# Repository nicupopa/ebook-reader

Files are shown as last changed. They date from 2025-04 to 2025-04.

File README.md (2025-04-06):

# OpenBook

## Block Diagram:
Block Diagram

## Bill of Materials:

|Component |Footprint |Link |
|---|---|---|
|BOOT_BUTTON  |BUTTON_CUSYOMV1 |https://industry.panasonic.com/global/en/products/control/switch/light-touch/number/evqpuj02k |
|C1 |ESP32_WROVER_EAGLE-LTSPICE_CC0402 |https://eu.mouser.com/ProductDetail/YAGEO/CC0402MRX5R5BB106?qs=zEY9bCHj09eCmUJdZuS5Lg%3D%3D |
|C1_BAT |ESP32_WROVER_EAGLE-LTSPICE_CC0402 |n/a |
|C1_BAT1 |EAGLE-LTSPICE_CC0402 |n/a |
|C1_BAT2 |EAGLE-LTSPICE_CC0402 |n/a |
|C2 |ESP32_WROVER_EAGLE-LTSPICE_CC0402 |n/a |
|C2_BAT\ |ESP32_WROVER_EAGLE-LTSPICE_CC0402 |n/a |
|C3 |RCL_CPOL-EUCT3528 |n/a |
|C4 |ESP32_WROVER_EAGLE-LTSPICE_CC0402 |n/a |
|C4_USB |ESP32_WROVER_EAGLE-LTSPICE_CC0402 |n/a |
|C5 |ESP32_WROVER_EAGLE-LTSPICE_CC0402 |n/a |
|C5_USB |ESP32_WROVER_EAGLE-LTSPICE_CC0402 |n/a |
|C6 |ESP32_WROVER_EAGLE-LTSPICE_CC0402 |n/a |
|C7 |ESP32_WROVER_EAGLE-LTSPICE_CC0402 |n/a |
|C8 |ESP32_WROVER_EAGLE-LTSPICE_CC0402 |n/a |
|C9 |EAGLE-LTSPICE_CC0402 |n/a |
|C10 |ESP32_WROVER_EAGLE-LTSPICE_CC0402 |n/a |
|C10_SUPERCAP |CPH3225A |https://www.snapeda.com/parts/CPH3225A/Seiko+Instruments/view-part/?ref=eda |
|CHANGE_BUTTON|BUTTON_CUSYOMV1 |https://industry.panasonic.com/global/en/products/control/switch-light-touch/number/evqpuj02k |
|CHG_LED |ADAFRUIT_LEDCHIP-LED0603 |https://www.snapeda.com/parts/KP-1608SURCK/Kingbright/view-part/?ref=search&t=LED%200603 |
|C_DELAY |ESP32_WROVER_EAGLE-LTSPICE_CC0402 |n/a |
|D1 |USBLC6-2SC6Y |https://www.snapeda.com/parts/USBLC6-2SC6Y/STMicroelectronics/view-part/?ref=eda |
|D2 |ESP32_WROVER_AVX---SD0805S020S1R0_AVX_... |https://eu.mouser.com/ProductDetail/KYOCERA-AVX/SD0805S020S1R0?qs=jCA%252BPfw4LHbpkAoSnwrdjw%3D%3D |
|D3 |MBR0530 |https://eu.mouser.com/ProductDetail/KYOCERA-AVX/SD0805S020S1R0?qs=jCA%252BPfw4LHbpkAoSnwrdjw%3D%3D |
|D4 |MBR0530 |https://www.snapeda.com/parts/MBR0530/Onsemi/view-part/?ref=eda |
|D5 |MBR0530 |https://www.snapeda.com/parts/MBR0530/Onsemi/view-part/?ref=eda |
|D6 |PGB1010603MR |https://www.snapeda.com/parts/PGB1010603MR/Littelfuse/view-part/?ref=eda |
|D7 |ESP32_WROVER_AVX---SD0805S020S1R0_AVX_... |https://eu.mouser.com/ProductDetail/KYOCERA-AVX/SD0805S020S1R0?qs=jCA%252BPfw4LHbpkAoSnwrdjw%3D%3D |
|D8 |PGB1010603MR |https://www.snapeda.com/parts/PGB1010603MR/Littelfuse/view-part/?ref=eda |
|D9 |PGB1010603MR |https://www.snapeda.com/parts/PGB1010603MR/Littelfuse/view-part/?ref=eda |
|D10 |PGB1010603MR |https://www.snapeda.com/parts/PGB1010603MR/Littelfuse/view-part/?ref=eda |
|D11 |PGB1010603MR |https://www.snapeda.com/parts/PGB1010603MR/Littelfuse/view-part/?ref=eda |
|D12 |PGB1010603MR |https://www.snapeda.com/parts/PGB1010603MR/Littelfuse/view-part/?ref=eda |
|EPD_C1 |ESP32_WROVER_EAGLE-LTSPICE_CC0402 |n/a |
|EPD_C2 |ESP32_WROVER_EAGLE-LTSPICE_CC0402 |n/a |
|EPD_C5 |ESP32_WROVER_EAGLE-LTSPICE_CC0402 |n/a |
|EPD_C6 |ESP32_WROVER_EAGLE-LTSPICE_CC0402 |n/a |
|EPD_C7 |ESP32_WROVER_EAGLE-LTSPICE_CC0402 |n/a |
|EPD_C8 |ESP32_WROVER_EAGLE-LTSPICE_CC0402 |n/a |
|EPD_C9 |ESP32_WROVER_EAGLE-LTSPICE_CC0402 |n/a |
|EPD_C10 |ESP32_WROVER_EAGLE-LTSPICE_CC0402 |n/a |
|EPD_C11 |ESP32_WROVER_EAGLE-LTSPICE_CC0402 |n/a |
|EPD_C12 |ESP32_WROVER_EAGLE-LTSPICE_CC0402 |n/a |
|IC1 |BD5229G-TR |https://componentsearchengine.com/part-view/BD5229G-TR/ROHM%20Semiconductor |
|IC4 |XC6220A331MR-G |https://componentsearchengine.com/part-view/XC6220A331MR-G/Torex |
|J1 |FH34SRJ-24S-0.5SH_99_ |https://componentsearchengine.com/part-view/XC6220A331MR-G/Torex |
|J2 |SAMACSYS_PARTS_USB4110-GF-A |https://componentsearchengine.com/part-view/USB4110-GF-A/GCT%20(GLOBAL%20CONNECTOR%20TECHNOLOGY |
|J3 |QWIIC_CONNECTORJS-1MM |n/a |
|J4 |112A-TAAR-R03_ATTEND |https://store.comet.srl.ro/Catalogue/Product/43497/ |
|L1 |744043680IND_4828-WE-TPC_WRE |https://eu.mouser.com/ProductDetail/Wurth-Elektronik/744043680?qs=PGXP4M47uW6VkZq%252BkzjrHA%3D%3D |
|PFMF.050.1 |ESP32C6_VARISTORCN1812 |https://www.mouser.co.uk/ProductDetail/EPCOS-TDK/B72520T0350K062?qs=dEfas%2FXlABIszF52uu7vrg%3D%3D |
|Q1 |ESP32_WROVER_SPARKFUN-DISCRETESEMI_MOSFET_...|https://componentsearchengine.com/part-view/DMG2305UX-7/Diodes%20Incorporated |
|Q2 |ESP32_WROVER_SPARKFUN-DISCRETESEMI_MOSFET_...|n/a |
|Q3 |D8 |https://componentsearchengine.com/part-view/SI1308EDL-T1-GE3/Vishay |
|R1 |ESP32_WROVER_EAGLE-LTSPICE_RR0402 |n/a |
|R1-PINH |ESP32_WROVER_EAGLE-LTSPICE_RR0402 |n/a |
|R1-PINH1 |ESP32_WROVER_EAGLE-LTSPICE_RR0402 |n/a |
|R1_BAT |ESP32_WROVER_EAGLE-LTSPICE_RR0402 |n/a |
|R1_PWRUSB |ESP32_WROVER_EAGLE-LTSPICE_RR0402 |n/a |
|R2 |ESP32_WROVER_EAGLE-LTSPICE_RR0402 |https://componentsearchengine.com/part-view/R0402%201%25%20100%20K%20(RC0402FR-07100KL |
|R2-PINH |ESP32_WROVER_EAGLE-LTSPICE_RR0402 |n/a |
|R2-PINH1 |ESP32_WROVER_EAGLE-LTSPICE_RR0402 |n/a |
|R2-USB |ESP32_WROVER_EAGLE-LTSPICE_RR0402 |n/a |
|R2-USB1 |ESP32_WROVER_EAGLE-LTSPICE_RR0402 |n/a |
|R2_BAT |ESP32_WROVER_EAGLE-LTSPICE_RR0402 |n/a |
|R3 |ESP32_WROVER_EAGLE-LTSPICE_RR0402 |n/a |
|R4 |ESP32_WROVER_EAGLE-LTSPICE_RR0402 |n/a |
|R5 |ESP32_WROVER_EAGLE-LTSPICE_RR0402 |n/a |
|R6 |ESP32_WROVER_EAGLE-LTSPICE_RR0402 |n/a |
|R7 |ESP32_WROVER_EAGLE-LTSPICE_RR0402 |n/a |
|R8 |ESP32_WROVER_EAGLE-LTSPICE_RR0402 |n/a |
|R9 |ESP32_WROVER_EAGLE-LTSPICE_RR0402 |n/a |
|R10 |ESP32_WROVER_EAGLE-LTSPICE_RR0402 |n/a |
|RESET_BUTTON |BUTTON_CUSYOMV1 |https://industry.panasonic.com/global/en/products/control/switch/light-touch/number/evqpuj02k |
|R_BOOT |ESP32_WROVER_EAGLE-LTSPICE_RR0402 |n/a |
|R_CAPACITOR  |ESP32_WROVER_EAGLE-LTSPICE_RR0402 |n/a |
|R_CHANGE |ESP32_WROVER_EAGLE-LTSPICE_RR0402 |n/a |
|R_CL1 |ESP32_WROVER_EAGLE-LTSPICE_RR0402 |n/a |
|R_RESET |ESP32_WROVER_EAGLE-LTSPICE_RR0402 |n/a |
|SENSOR2 |ESP32_WROVER_BME680_BME680 |https://www.snapeda.com/parts/BME680/Bosch/view-part/?welcome=home |
|SJ1 |SJ |https://grabcad.com/library/solder-jumpers-1 |
|U1 |W25Q512JVEIQ |https://www.snapeda.com/parts/W25Q512JVEIQ/Winbond+Electronics/view-part/?ref=eda |
|U2 |ESP32-C6-WROOM-1-N8 |https://www.snapeda.com/parts/ESP32-C6-WROOM-1-N8/Espressif+Systems/view-part/?ref=eda |
|U3 |DS3231SN# |https://www.snapeda.com/parts/DS3231SN%23/Analog+Devices/view-part/?ref=eda |
|U4 |MAX17048G+T10 |https://www.snapeda.com/parts/MAX17048G+T10/Analog+Devices/view-part/?ref=eda |
|U5 |ESP32_WROVER_SPARKFUN-IC-POWER_MCP73831 |https://eu.mouser.com/ProductDetail/Microchip-Technology/MCP73831T-2ACI-OT?qs=yUQqVecv4qvbBQBGbHx0Mw%3D%3Dcf|

## Detailed Hardware Description/Specs:

### Microcontroller – ESP32-C6-WROOM-1-N8

- **Processor:** 32-bit RISC-V, up to 160 MHz  
- **Memory:** 512 KB internal SRAM, 8 MB external flash (W25Q512JVEIQ)  
- **Connectivity:** Wi-Fi 6 (802.11ax), Bluetooth 5 (LE), IEEE 802.15.4 (Thread/Zigbee), USB 2.0 (Full-Speed)  
- **Peripherals:** SPI, I²C, UART, PWM, ADC, multiple GPIOs  

### External Memory – W25Q512JVEIQ

- **Capacity:** 512 Mbit (64 MB)  
- **Interface:** Quad SPI (QPI)  
- **Operating Frequency:** Up to 133 MHz  
- **Supply Voltage:** 2.7 V to 3.6 V  
- **Features:** high endurance (100k write/erase cycles)

### Real-Time Clock – DS3231SN#

- **Accuracy:** ±2 ppm from 0°C to +40°C  
- **Interface:** I²C  
- **Features:** Integrated temperature-compensated crystal oscillator (TCXO)  
- **Voltage Range:** 2.3 V to 5.5 V  
- **Additional:** Battery backup support, 2 programmable alarms, 1Hz square wave output

### Battery Monitor – MAX17048G+T10

- **Function:** Fuel gauge for single-cell Li-ion/Li-Po batteries
- **Interface:** I²C  
- **Voltage Range:** 2.5 V to 4.5 V  
- **Power Consumption:** Ultra-low quiescent current (~23 µA)

### Charge Controller – MCP73831

- **Battery Type:** Single-cell Li-ion/Li-Po  
- **Charging Current:** Programmable up to 500 mA  
- **Interface:** Standalone (no I²C/SPI)  
- **Input Voltage:** 3.75 V to 6 V  
- **Status Output:** Charge status indication via LED

### Environmental Sensor – BME688

- **Measurements:** Temperature, humidity, pressure, gas (VOC, air quality)  
- **Interface:** I²C, SPI  
- **Temperature Range:** -40 °C to +85 °C  
- **Gas Sensor:** AI-based VOC and gas mixture detection  
- **Power Consumption:** Ultra-low power (ideal for mobile/wearables)

### E-Paper Display

- **Interface:** SPI  
- **Resolution:** 800×480
- **Power Usage:** Extremely low (only consumes power during refresh)  
- **Features:** Excellent sunlight readability, wide viewing angles

### Qwiic Connector

- **Type:** JST SH 1.0 mm 4-pin connector  
- **Purpose:** Standardized I²C interconnect for sensors/modules  
- **Voltage:** 3.3 V logic  
- **Pins:** SDA, SCL, VCC, GND  

### SD Memory Card Connector – 112A-TAAR-R03

- **Type:** MicroSD card socket
- **Interface:** SPI or SDIO  
- **Voltage:** Typically 3.3 V logic  
- **Features:** Push-push eject mechanism, card detect switch  
- **Use Case:** Data logging, file storage, media playback

## ESP32-C6 Pin Usage:

| Device | ESP32-C6 Pin | Connected Component | Function |
|:---|:---|:---|:---|
| U2 - ESP32-C6 | GPIO0 | BOOT button | Enables bootloader mode on startup (input)  |
| U2 - ESP32-C6 | GPIO1 | UART TX | Serial communication for debugging/flashing |
| U2 - ESP32-C6 | GPIO2 | UART RX | Serial communication for debugging/flashing |
| U2 - ESP32-C6 | GPIO3 | BME688 (I²C SDA) | Environmental sensor data line |
| U2 - ESP32-C6 | GPIO4 | BME688 (I²C SCL) | Environmental sensor clock line |
| U2 - ESP32-C6 | GPIO5 | MAX17048 (I²C SDA) | Battery monitor data line (shared bus) |
| U2 - ESP32-C6 | GPIO6 | MAX17048 (I²C SCL) | Battery monitor clock line (shared bus) |
| U2 - ESP32-C6 | GPIO7 | Qwiic Connector SDA | I²C communication (shared with sensors) |
| U2 - ESP32-C6 | GPIO8 | Qwiic Connector SCL | I²C communication (shared with sensors) |
| U2 - ESP32-C6 | GPIO9 | DS3231 RTC SDA | I²C data line for real-time clock |
| U2 - ESP32-C6 | GPIO10 | DS3231 RTC SCL | I²C clock line for real-time clock |
| U2 - ESP32-C6 | GPIO18 | E-Paper Display (SPI MOSI) | Serial data out to display |
| U2 - ESP32-C6 | GPIO19 | E-Paper Display (SPI CLK)  | Serial clock for display communication |
| U2 - ESP32-C6 | GPIO20 | E-Paper Display (CS) | Chip select line |
| U2 - ESP32-C6 | GPIO21 | E-Paper Display (DC) | Data/Command control pin |
| U2 - ESP32-C6 | GPIO22 | E-Paper Display (RST) | Reset line for display |
| U2 - ESP32-C6 | GPIO23 | E-Paper Display (BUSY) | Busy status signal input |
| U2 - ESP32-C6 | GPIO13 | SD Card (SPI CS) | Chip select line for SD card |
| U2 - ESP32-C6 | GPIO14 | SD Card (SPI MISO) | Master In Slave Out - reads from SD |
| U2 - ESP32-C6 | GPIO15 | SD Card (SPI MOSI) | Master Out Slave In - writes to SD |
| U2 - ESP32-C6 | GPIO16 | SD Card (SPI CLK) | SPI clock for SD card communication |

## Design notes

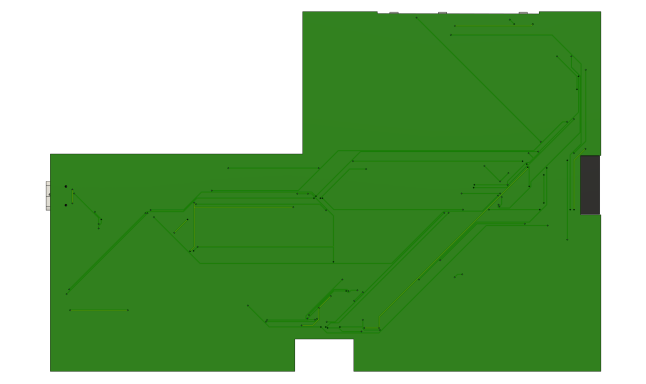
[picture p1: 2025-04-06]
Images/pcb_view_bottom.png

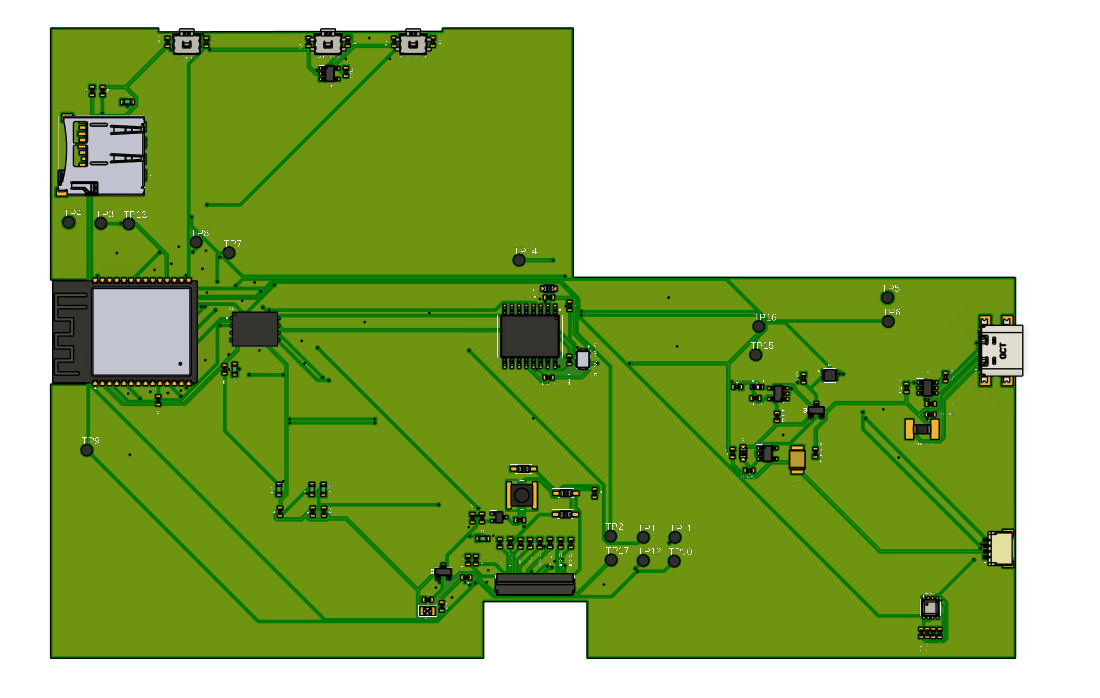
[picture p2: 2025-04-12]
Images/3D_PCB.png

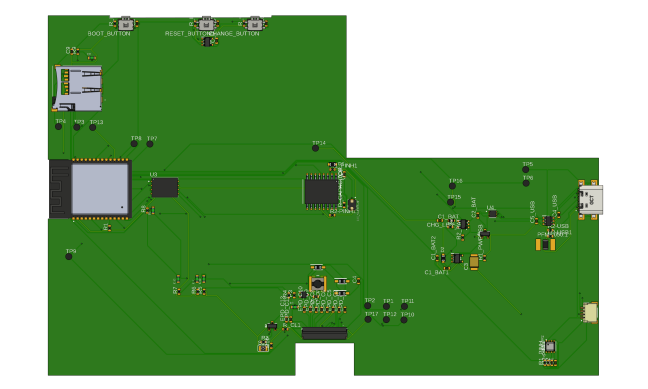
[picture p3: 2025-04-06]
Images/pcb_view_top.png

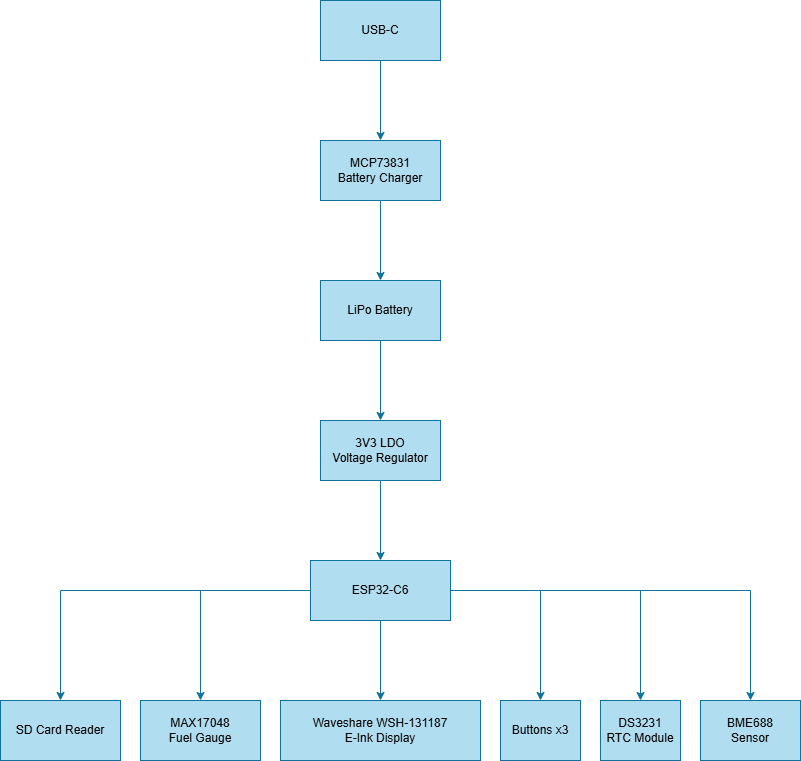
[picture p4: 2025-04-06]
Images/Block Diagram.png

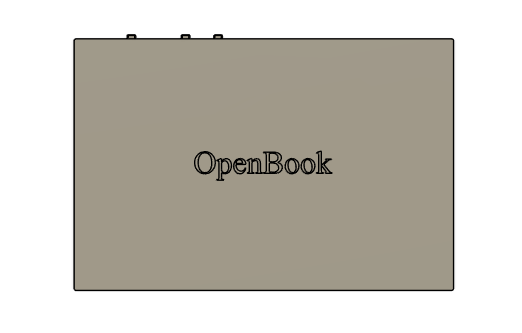
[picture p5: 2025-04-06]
Images/case_view_bottom.png

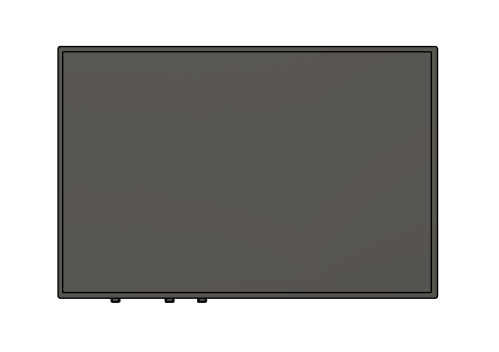
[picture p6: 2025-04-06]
Images/case_view_top.png

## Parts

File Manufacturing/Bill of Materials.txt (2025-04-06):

Partlist exported from Fusion Hub: nicu   Project: OPENBOOK  Board: PCB v40 at 06/04/2025 15:30

Qty Value                                                                          Device                                                                         Package                                                Parts                                                                                       Description                                                                                                                                                                                                                                                                                                                                                                                                                                                                                          ARROW_PART_NUMBER ARROW_PRICE-STOCK AVAILABILITY CENTROID_NOT_SPECIFIED CHECK_PRICES                                                                           COPYRIGHT                                                DATASHEET                              DESCRIPTION                                                                                        DIGIKEY_DESCRIPTION                                                                                                                                                                                                      DIGIKEY_PART_NUMBER                           HEIGHT                                                                                LEAD_FREE                                                          MANUFACTURER   MANUFACTURER_NAME                 MANUFACTURER_PART_NUMBER MF                  MFR_NAME          MOUSER_PART_NUMBER    MOUSER_PRICE-STOCK                                                                                        MOUSER_TESTING_PART_NUMBER MOUSER_TESTING_PRICE-STOCK MP                                                                                                                  MPN                                                                                                  PACKAGE                     POPULARITY          PREFIX PRICE                        PROD_ID    PURCHASE-URL                                                                                                                                ROHS SNAPEDA_LINK                                                                       SPICEMODEL                                                                                                                                      SPICEPREFIX TEMPERATURE_RANGE_HIGH                                                                  TEMPERATURE_RANGE_LOW TP_SIGNAL_NAME VALUE             
1                                                                                  ADAFRUIT_LEDCHIP-LED0603                                                       ADAFRUIT_CHIP-LED0603                                  CHG_LED                                                                                     LED                                                                                                                                                                                                                                                                                                                                                                                                                                                                                                                                                                                                                                                                                                                                                                                                                                                                                                                                                                                                                                                                                                                                                                                                                                                                                                                                                                                                                                                                                                                                                                                                                                                                                                                                                                                                                                                                                                                                                                                                                                                                                                                                                                                                                                                                                                                                                                                                                                                                                 
3                                                                                  BUTTON_CUSYOMV1                                                                MYBUTTON                                               BOOT_BUTTON, CHANGE_BUTTON, RESET_BUTTON                                                                                                                                                                                                                                                                                                                                                                                                                                                                                                                                                                                                                                                                                                                                                                                                                                                                                                                                                                                                                                                                                                                                                                                                                                                                                                                                                                                                                                                                                                                                                                                                                                                                                                                                                                                                                                                                                                                                                                                                                                                                                                                                                                                                                                                                                                                                                                                                                                                                                                                                        
1                                                                                  ESP32_WROVER_EAGLE-LTSPICE_RR0402                                              ESP32_WROVER_EAGLE-LTSPICE_R0402                       R1                                                                                          RESISTOR, European symbol                                                                                                                                                                                                                                                                                                                                                                                                                                                                                                                                                                                                                                                                                                                                                                                                                                                                                                                                                                                                                                                                                                                                                                                                                                                                                                                                                                                                                                                                                                                                                                                                                                                                                                                                                                                                                                                                                                                                                                                                                                                                                                                                                NONE                                                                                                                                            R                                                                                                                                                          
1                                                                                  SJ                                                                             SJ                                                     SJ1                                                                                         SMD solder JUMPER                                                                                                                                                                                                                                                                                                                                                                                                                                                                                                                                                                                                                                                                                                                                                                                                                                                                                                                                                                                                                                                                                                                                                                                                                                                                                                                                                                                                                                                                                                                                                                                                                                                                                                                                                                                                                                                 3                                                                                                                                                                                                                                                                                                                                                                                                                                                                                                                                                                                                                 
1   0.1uF/50V                                                                      EAGLE-LTSPICE_CC0402                                                           EAGLE-LTSPICE_C0402                                    EPD_C5                                                                                      CAPACITOR, European symbol                                                                                                                                                                                                                                                                                                                                                                                                                                                                                                                                                                                                                                                                                                                                                                                                                                                                                                                                                                                                                                                                                                                                                                                                                                                                                                                                                                                                                                                                                                                                                                                                                                                                                                                                                                                                                                                                                                                                                                                                                                                                                                                                               NONE                                                                                                                                            C                                                                                                                                                          
1   0.47                                                                           ESP32_WROVER_EAGLE-LTSPICE_RR0402                                              ESP32_WROVER_EAGLE-LTSPICE_R0402                       R3                                                                                          RESISTOR, European symbol                                                                                                                                                                                                                                                                                                                                                                                                                                                                                                                                                                                                                                                                                                                                                                                                                                                                                                                                                                                                                                                                                                                                                                                                                                                                                                                                                                                                                                                                                                                                                                                                                                                                                                                                                                                                                                                                                                                                                                                                                                                                                                                                                NONE                                                                                                                                            R                                                                                                                                                          
1   100K                                                                           ESP32_WROVER_EAGLE-LTSPICE_RR0402                                              ESP32_WROVER_EAGLE-LTSPICE_R0402                       R1_PWRUSB                                                                                   RESISTOR, European symbol                                                                                                                                                                                                                                                                                                                                                                                                                                                                                                                                                                                                                                                                                                                                                                                                                                                                                                                                                                                                                                                                                                                                                                                                                                                                                                                                                                                                                                                                                                                                                                                                                                                                                                                                                                                                                                                                                                                                                                                                                                                                                                                                                NONE                                                                                                                                            R                                                                                                                                                          
7   100nF                                                                          EAGLE-LTSPICE_CC0402                                                           EAGLE-LTSPICE_C0402                                    C1, C2, C4_USB, C6, C8, C10, C_DELAY                                                        CAPACITOR, European symbol                                                                                                                                                                                                                                                                                                                                                                                                                                                                                                                                                                                                                                                                                                                                                                                                                                                                                                                                                                                                                                                                                                                                                                                                                                                                                                                                                                                                                                                                                                                                                                                                                                                                                                                                                                                                                                                                                                                                                                                                                                                                                                                                               NONE                                                                                                                                            C                                                                                                                                                          
1   100nF                                                                          ESP32_WROVER_EAGLE-LTSPICE_CC0402                                              ESP32_WROVER_EAGLE-LTSPICE_C0402                       C9                                                                                          CAPACITOR, European symbol                                                                                                                                                                                                                                                                                                                                                                                                                                                                                                                                                                                                                                                                                                                                                                                                                                                                                                                                                                                                                                                                                                                                                                                                                                                                                                                                                                                                                                                                                                                                                                                                                                                                                                                                                                                                                                                                                                                                                                                                                                                                                                                                               NONE                                                                                                                                            C                                                                                                                                                          
1   100uF TANT                                                                     RCL_CPOL-EUCT3528                                                              RCL_CT3528                                             C3                                                                                          POLARIZED CAPACITOR, European symbol                                                                                                                                                                                                                                                                                                                                                                                                                                                                                                                                                                                                                                                                                                                                                                                                                                                                                                                                                                                                                                                                                                                                                                                                                                                                                                                                                                                                                                                                                                                                                                                                                                                                                                                                                                                                                              0                                                                                                                                                                                                                                                                                                                                                                                                                                                      C
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

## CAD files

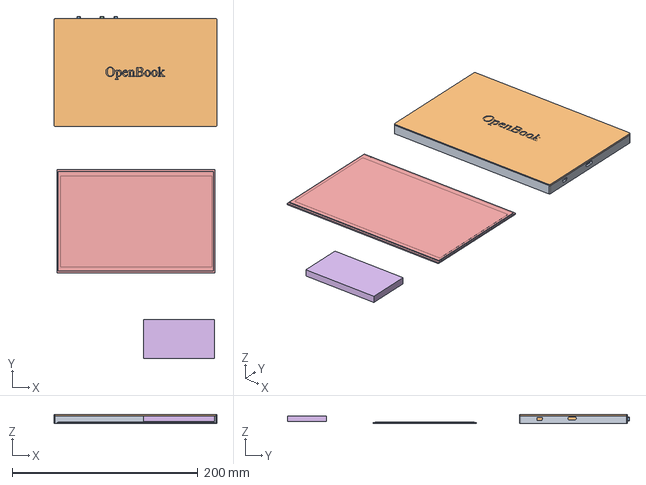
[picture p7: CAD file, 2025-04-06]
Mechanical/OpenBook_exploded.step
175.3 x 368.2 x 9.86 mm

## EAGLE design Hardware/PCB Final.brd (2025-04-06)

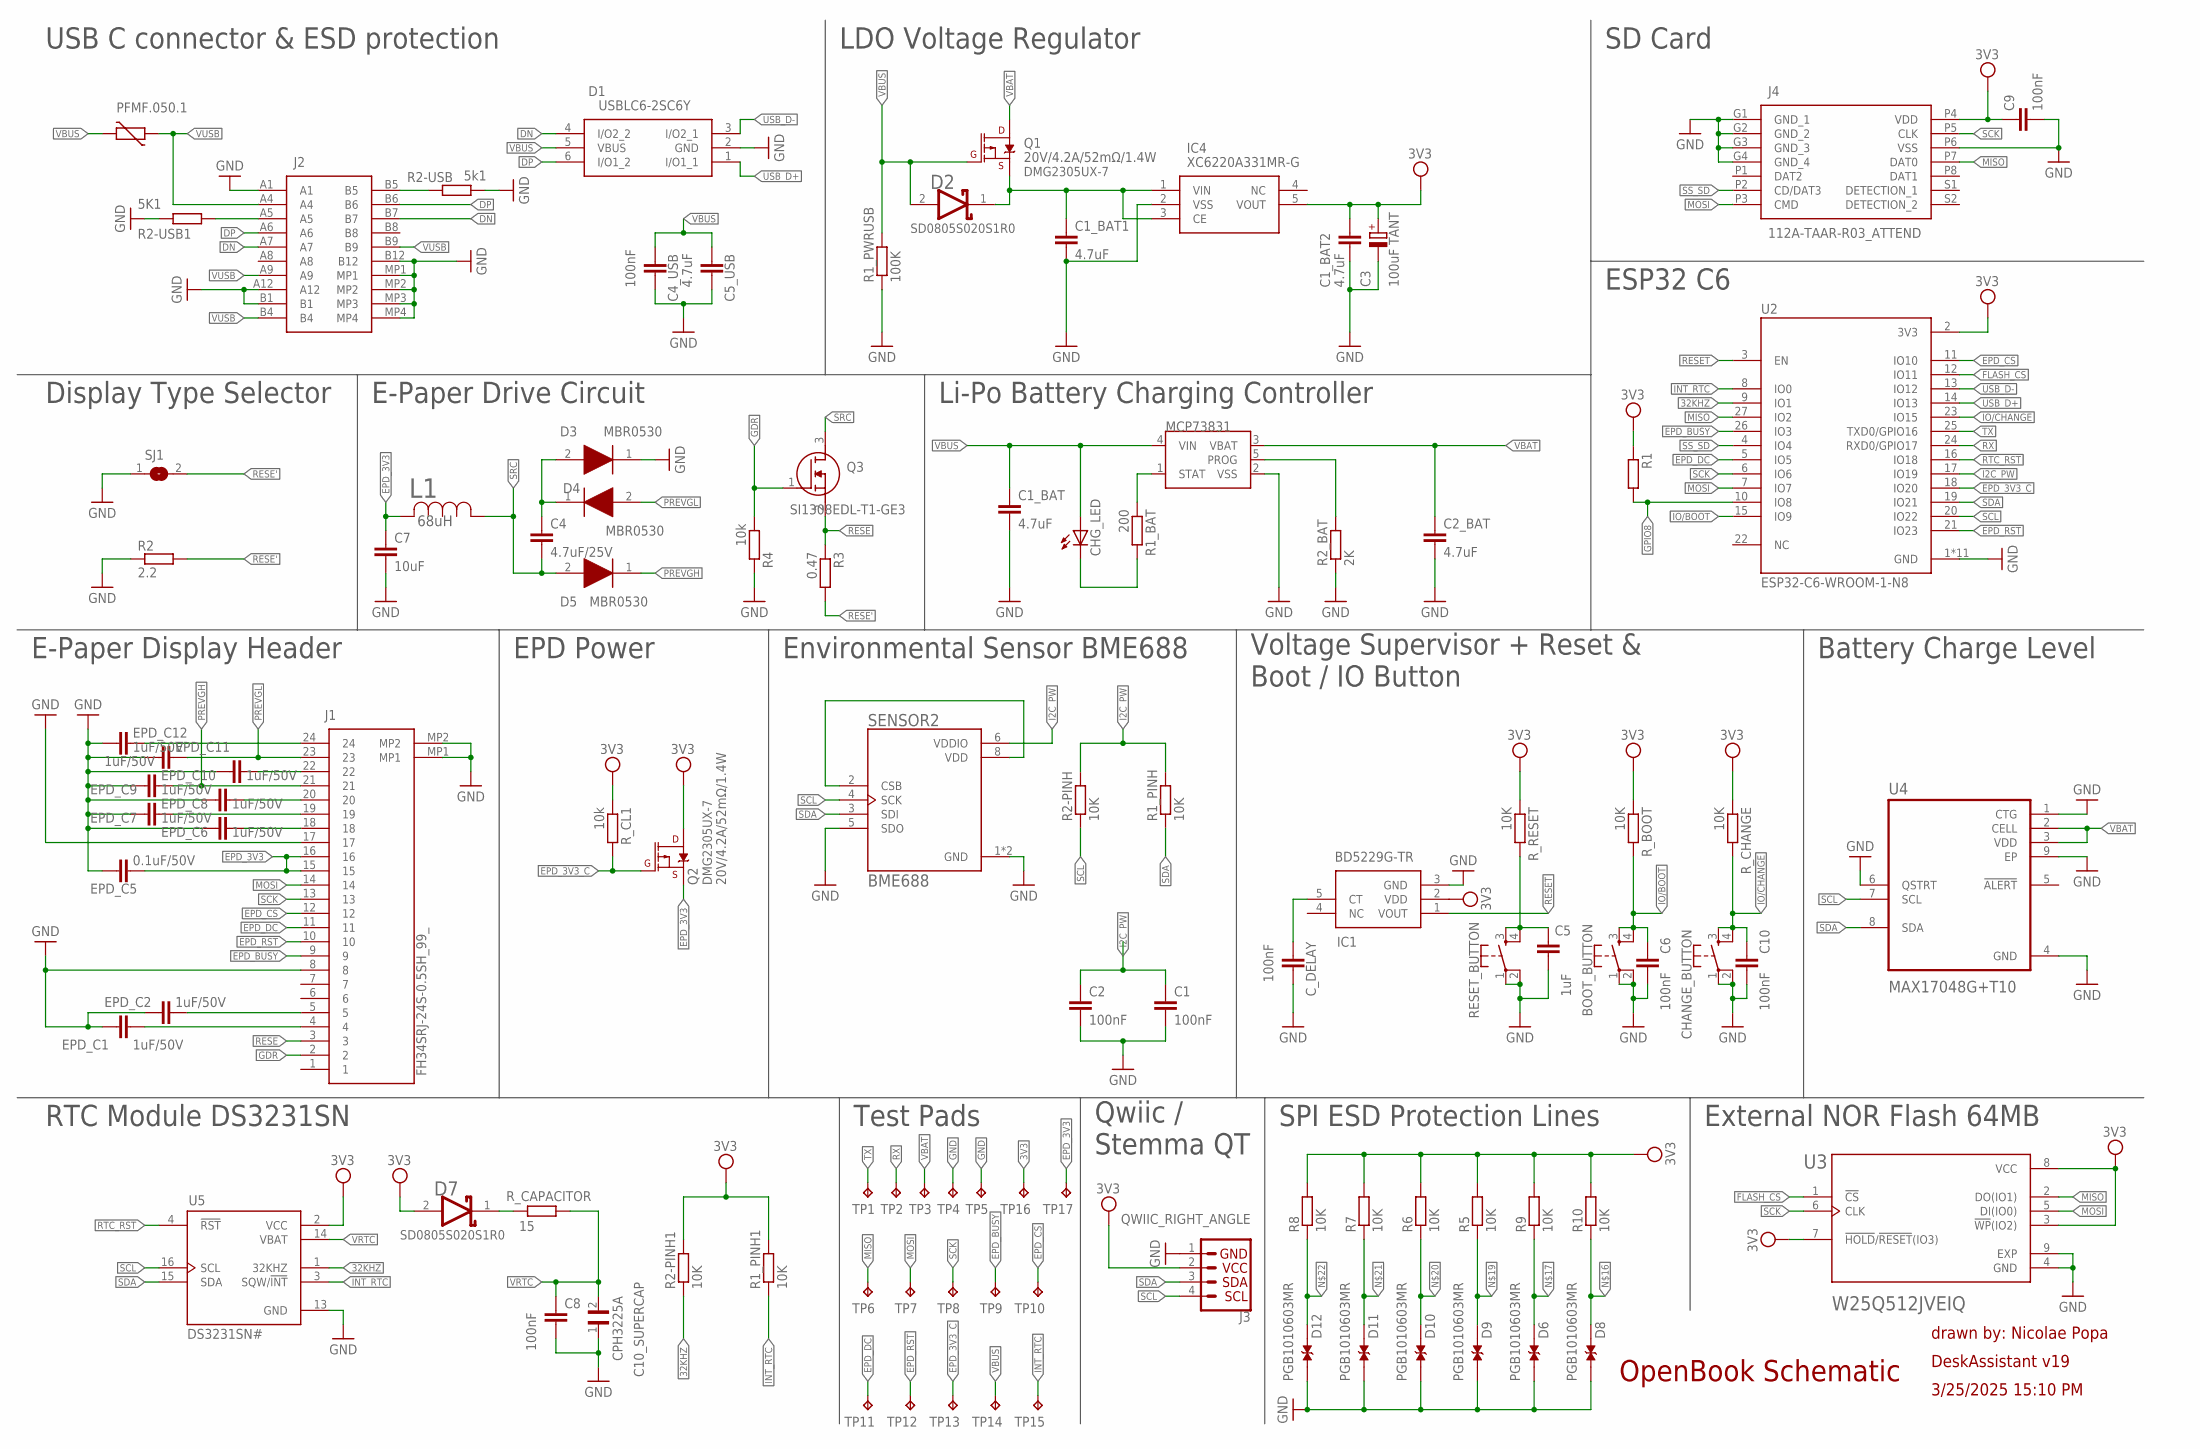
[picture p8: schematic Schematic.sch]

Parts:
BOOT_BUTTON: BUTTON_CUSYOMV1; MYBUTTON
C1, C2, C4_USB, C6, C8, C10: 100nF; EAGLE-LTSPICE_C0402
C1_BAT, C1_BAT1, C1_BAT2, C2_BAT, C5_USB: 4.7uF; EAGLE-LTSPICE_C0402
C3: 100uF TANT; RCL_CT3528
C4: 4.7uF/25V; EAGLE-LTSPICE_C0402
C5: 1uF; EAGLE-LTSPICE_C0402
C7: 10uF; EAGLE-LTSPICE_C0402
C9: 100nF; ESP32_WROVER_EAGLE-LTSPICE_C0402
C10_SUPERCAP: CPH3225A; CAPCP3225X100N
CHANGE_BUTTON: BUTTON_CUSYOMV1; MYBUTTON
CHG_LED: ADAFRUIT_LEDCHIP-LED0603; ADAFRUIT_CHIP-LED0603
C_DELAY: 100nF; EAGLE-LTSPICE_C0402
D1: USBLC6-2SC6Y; SOT95P280X145-6N
D2: ESP32_WROVER_AVX---SD0805S020S1R0_AVX_SD0805S020S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; ESP32_WROVER_AVX---SD0805S020S1R0_AVX_SD0805S020S1R0_0
D3, D4, D5: MBR0530; SOD3716X135N
D6, D8, D9, D10, D11, D12: PGB1010603MR; DIOC1608X36N
D7: SD0805S020S1R0; ESP32_WROVER_AVX---SD0805S020S1R0_AVX_SD0805S020S1R0_0
EPD_C1, EPD_C2, EPD_C6, EPD_C7, EPD_C8, EPD_C9, EPD_C10, EPD_C11, EPD_C12: 1uF/50V; EAGLE-LTSPICE_C0402
EPD_C5: 0.1uF/50V; EAGLE-LTSPICE_C0402
IC1: BD5229G-TR; SOT95P280X125-5N
IC4: XC6220A331MR-G; SOT95P280X120-5N
J1: FH34SRJ-24S-0.5SH_99_; FH34SRJ24S05SH99
J2: SAMACSYS_PARTS_USB4110-GF-A; SAMACSYS_PARTS_USB4110GFA
J3: QWIIC_RIGHT_ANGLE; JST04_1MM_RA
J4: 112A-TAAR-R03_ATTEND; 112ATAARR03ATTEND
L1: 68uH; IND_4828-WE-TPC_WRE
PFMF.050.1: ESP32C6_VARISTORCN1812; ESP32C6_VARISTOR_CT/CN1812
Q1, Q2: 20V/4.2A/52mΩ/1.4W; ESP32_WROVER_SPARKFUN-DISCRETESEMI_SOT23-3
Q3: SI1308EDL-T1-GE3; SOT65P210X110-3N
R1: ESP32_WROVER_EAGLE-LTSPICE_RR0402; ESP32_WROVER_EAGLE-LTSPICE_R0402
R1_BAT: 200; ESP32_WROVER_EAGLE-LTSPICE_R0402
R1_PINH, R1_PINH1, R2-PINH, R2-PINH1, R5, R6, R7, R8, R9, R10: 10K; ESP32_WROVER_EAGLE-LTSPICE_R0402
R1_PWRUSB: 100K; ESP32_WROVER_EAGLE-LTSPICE_R0402
R2: 2.2; ESP32_WROVER_EAGLE-LTSPICE_R0402
R2-USB: 5k1; ESP32_WROVER_EAGLE-LTSPICE_R0402
R2-USB1: 5K1; ESP32_WROVER_EAGLE-LTSPICE_R0402
R2_BAT: 2K; ESP32_WROVER_EAGLE-LTSPICE_R0402
R3: 0.47; ESP32_WROVER_EAGLE-LTSPICE_R0402
R4: 10k; ESP32_WROVER_EAGLE-LTSPICE_R0402
RESET_BUTTON: BUTTON_CUSYOMV1; MYBUTTON
R_BOOT: 10K; ESP32_WROVER_EAGLE-LTSPICE_R0402
R_CAPACITOR: 15; ESP32_WROVER_EAGLE-LTSPICE_R0402
R_CHANGE: 10K; ESP32_WROVER_EAGLE-LTSPICE_R0402
R_CL1: 10k; ESP32_WROVER_EAGLE-LTSPICE_R0402
R_RESET: 10K; ESP32_WROVER_EAGLE-LTSPICE_R0402
SENSOR2: BME688; ESP32_WROVER_BME680_PSON80P300X300X100-8N
SJ1: SJ
TP1, TP2, TP3, TP4, TP5, TP6, TP7, TP8, TP9, TP10, TP11, TP12, TP13, TP14, TP15, TP16, TP17: TPTP20R; TP20R
U1: MCP73831; ESP32_WROVER_SPARKFUN-IC-POWER_SOT23-5
U2: ESP32-C6-WROOM-1-N8; XCVR_ESP32-C6-WROOM-1-N8
U3: W25Q512JVEIQ; SON127P600X800X80-9N
U4: MAX17048G+T10; SON50P200X200X80-9N
U5: DS3231SN#; SOIC127P1032X265-16N

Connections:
3V3: C1_BAT2.1, C3.+, C9.1, D7.2 (ANODE), IC1.2 (VDD), IC4.5 (VOUT), J3.2, J4.P4 (VDD), Q2.3 (D), R1.1, R1_PINH1.2, R2-PINH1.2, R5.2, R6.2, R7.2, R8.2, R9.2, R10.2, R_BOOT.1, R_CHANGE.1, R_CL1.1, R_RESET.1, TP16.TP, U2.2 (3V3), U3.3 (!WP!(IO2)), U3.7 (!HOLD!/!RESET!(IO3)), U3.8 (VCC), U5.2 (VCC)
32KHZ: R2-PINH1.1, U2.9 (IO1), U5.1 (32KHZ)
DN: D1.4 (I/O2_2), J2.A7, J2.B7
DP: D1.6 (I/O1_2), J2.A6, J2.B6
EPD_3V3: C7.1, EPD_C5.1, J1.15, J1.16, L1.2, Q2.2 (S), TP17.TP
EPD_3V3_C: Q2.1 (G), R_CL1.2, TP13.TP, U2.18 (IO20)
EPD_BUSY: J1.9, TP9.TP, U2.26 (IO3)
EPD_CS: J1.12, TP10.TP, U2.11 (IO10)
EPD_DC: J1.11, TP11.TP, U2.5 (IO5)
EPD_RST: J1.10, TP12.TP, U2.21 (IO23)
FLASH_CS: U2.12 (IO11), U3.1 (!CS)
GDR: J1.2, Q3.1 (G), R4.1
GND: BOOT_BUTTON.1, BOOT_BUTTON.2, C1.2, C1_BAT.2, C1_BAT1.2, C1_BAT2.2, C2.2, C2_BAT.2, C3.-, C4_USB.2, C5.2, C5_USB.2, C6.2, C7.2, C8.2, C9.2, C10.2, C10_SUPERCAP.1, CHANGE_BUTTON.1, CHANGE_BUTTON.2, C_DELAY.2, D1.2 (GND), D3.1 (K), D6.1, D8.1, D9.1, D10.1, D11.1, D12.1, EPD_C1.2, EPD_C2.2, EPD_C5.2, EPD_C6.2, EPD_C7.2, EPD_C8.2, EPD_C9.2, EPD_C10.2, EPD_C11.2, EPD_C12.2, IC1.3 (GND), IC4.2 (VSS), J1.8, J1.17, J1.MP1, J1.MP2, J2.A1, J2.A12, J2.B1, J2.B12, J2.MP1, J2.MP2, J2.MP3, J2.MP4, J3.1, J4.G1 (GND_1), J4.G2 (GND_2), J4.G3 (GND_3), J4.G4 (GND_4), J4.P6 (VSS), R1_PWRUSB.1, R2.1, R2-USB.2, R2-USB1.1, R2_BAT.1, R4.2, RESET_BUTTON.1, RESET_BUTTON.2, SENSOR2.1 (GND), SENSOR2.5 (SDO), SENSOR2.7 (GND), SJ1.1, TP4.TP, TP5.TP, U1.2 (VSS), U2.1 (GND), U2.28 (GND), U2.29_1 (GND), U2.29_2 (GND), U2.29_3 (GND), U2.29_4 (GND), U2.29_5 (GND), U2.29_6 (GND), U2.29_7 (GND), U2.29_8 (GND), U2.29_9 (GND), U3.4 (GND), U3.9 (EXP), U4.1 (CTG), U4.4 (GND), U4.6 (QSTRT), U4.9 (EP), U5.13 (GND)
GPIO8: R1.2, U2.10 (IO8)
I2C_PW: C1.1, C2.1, R1_PINH.2, R2-PINH.2, SENSOR2.6 (VDDIO), U2.17 (IO19)
INT_RTC: R1_PINH1.1, TP15.TP, U2.8 (IO0), U5.3 (SQW/!INT)
IO/BOOT: BOOT_BUTTON.3, BOOT_BUTTON.4, C6.1, R_BOOT.2, U2.15 (IO9)
IO/CHANGE: C10.1, CHANGE_BUTTON.3, CHANGE_BUTTON.4, R_CHANGE.2, U2.23 (IO15)
MISO: J4.P7 (DAT0), TP6.TP, U2.27 (IO2), U3.2 (DO(IO1))
MOSI: J1.14, J4.P3 (CMD), TP7.TP, U2.7 (IO7), U3.5 (DI(IO0))
unnamed: J2.A5, R2-USB1.2
unnamed: C1_BAT1.1, D2.1 (CATHODE), IC4.1 (VIN), IC4.3 (CE), Q1.2 (S)
unnamed: R1_BAT.1, U1.1 (STAT)
unnamed: C4.1, D3.2 (A), D4.1 (K)
unnamed: CHG_LED.C, R1_BAT.2
unnamed: EPD_C12.1, J1.24
unnamed: R2_BAT.2, U1.5 (PROG)
unnamed: SENSOR2.2 (CSB), SENSOR2.8 (VDD)
unnamed: C_DELAY.1, IC1.5 (CT)
unnamed: EPD_C10.1, J1.22
unnamed: EPD_C8.1, J1.20
unnamed: EPD_C7.1, J1.19
unnamed: J2.B5, R2-USB.1
unnamed: EPD_C6.1, J1.18
unnamed: D8.2, R10.1
unnamed: D6.2, R9.1
unnamed: C5.1, RESET_BUTTON.3, RESET_BUTTON.4, R_RESET.2
unnamed: D9.2, R5.1
unnamed: D10.2, R6.1
unnamed: D11.2, R7.1
unnamed: D12.2, R8.1
unnamed: EPD_C2.1, J1.5
unnamed: EPD_C1.1, J1.4
unnamed: D7.1 (CATHODE), R_CAPACITOR.2
PREVGH: D5.1 (K), EPD_C9.1, J1.21
PREVGL: D4.2 (A), EPD_C11.1, J1.23
RESE: J1.3, Q3.2 (S), R3.1
RESE': R2.2, R3.2, SJ1.2
RESET: IC1.1 (VOUT), U2.3 (EN)
RTC_RST: U2.16 (IO18), U5.4 (!RST)
RX: TP2.TP, U2.24 (RXD0/GPIO17)
SCK: J1.13, J4.P5 (CLK), TP8.TP, U2.6 (IO6), U3.6 (CLK)
SCL: J3.4, R2-PINH.1, SENSOR2.4 (SCK), U2.20 (IO22), U4.7 (SCL), U5.16 (SCL)
SDA: J3.3, R1_PINH.1, SENSOR2.3 (SDI), U2.19 (IO21), U4.8 (SDA), U5.15 (SDA)
SRC: C4.2, D5.2 (A), L1.1, Q3.3 (D)
SS_SD: J4.P2 (CD/DAT3), U2.4 (IO4)
TX: TP1.TP, U2.25 (TXD0/GPIO16)
USB_D+: D1.1 (I/O1_1), U2.14 (IO13)
USB_D-: D1.3 (I/O2_1), U2.13 (IO12)
VBAT: C2_BAT.1, Q1.3 (D), TP3.TP, U1.3 (VBAT), U4.2 (CELL), U4.3 (VDD)
VBUS: C1_BAT.1, C4_USB.1, C5_USB.1, CHG_LED.A, D1.5 (VBUS), D2.2 (ANODE), PFMF.050.1.2, Q1.1 (G), R1_PWRUSB.2, TP14.TP, U1.4 (VIN)
VRTC: C8.1, C10_SUPERCAP.2, R_CAPACITOR.1, U5.14 (VBAT)
VUSB: J2.A4, J2.A9, J2.B4, J2.B9, PFMF.050.1.1

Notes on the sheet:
USB C connector & ESD protection
Display Type Selector
E-Paper Drive Circuit
LDO Voltage Regulator
SD Card
Li-Po Battery Charging Controller
ESP32 C6
E-Paper Display Header
EPD Power
Environmental Sensor BME688
Voltage Supervisor + Reset & Boot / IO Button
Battery Charge Level
RTC Module DS3231SN
Test Pads
Qwiic / Stemma QT
External NOR Flash 64MB
SPI ESD Protection Lines
OpenBook Schematic
drawn by: Nicolae Popa
DeskAssistant v19
3/25/2025 15:10 PM

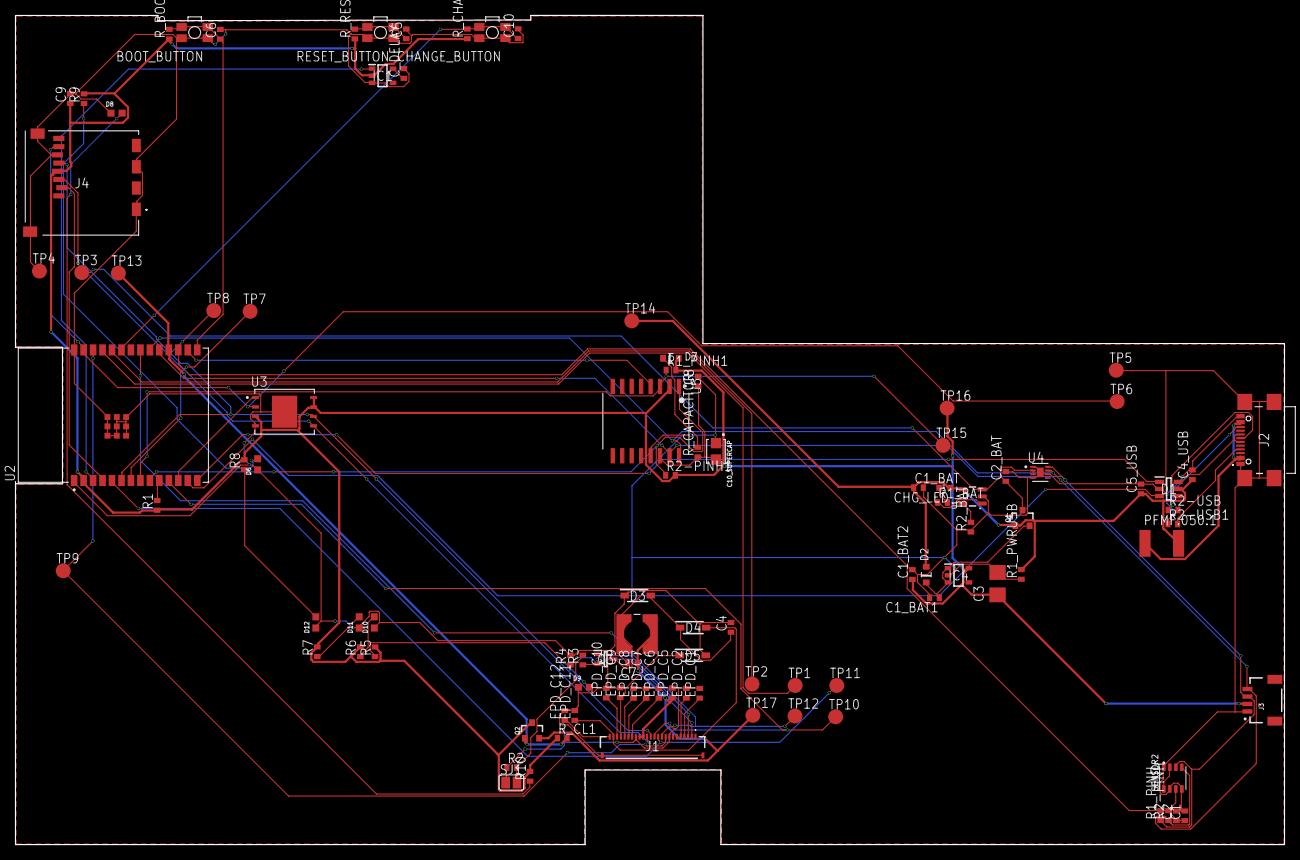
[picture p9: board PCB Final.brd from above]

Board: 2 copper layers, 170.2 x 111.2 mm, 103 parts (0 on the bottom side), 63 nets.

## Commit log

2025-03-29 Add schematic implementation
    [Schematic.sch]
2025-03-29 Add Schematic.sch
    [Schematic.sch]
2025-04-04 Add PCB
    [PCB_v19.brd]
2025-04-05 Update Schematic and PCB
    [PCB.brd, Schematic.sch]
2025-04-06 Update PCB and Schematic
    [PCB.brd, Schematic.sch]
2025-04-06 Update PCB
    [PCB Final.brd]
2025-04-06 Add manufacturing files
    [PnP_PCB.csv]
2025-04-06 Remove old files
    [PCB.brd]
2025-04-06 Add minor tweaks
    [PCB.brd]
2025-04-06 Add exploded version
    [OpenBook_exploded.step]
2025-04-12 Solve schematic issue
    [Schematic.sch]
2025-04-12 Fix PCB issues
    [PCB.brd]
2025-04-12 Fix enclosure and battery

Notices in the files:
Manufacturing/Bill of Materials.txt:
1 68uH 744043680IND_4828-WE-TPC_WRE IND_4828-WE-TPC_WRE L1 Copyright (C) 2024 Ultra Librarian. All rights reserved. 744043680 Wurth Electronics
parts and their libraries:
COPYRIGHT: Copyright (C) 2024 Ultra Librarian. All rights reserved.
